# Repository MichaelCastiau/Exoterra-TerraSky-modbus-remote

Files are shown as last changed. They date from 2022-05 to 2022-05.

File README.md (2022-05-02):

# Exoterra Terrasky IR modbus enabled remote

These are the hardware schematics for a STM32 powered 38kHz IR remote that can 'learn' and then send out specfic signals for day, night and twilight lighting effects for the Exo Terrasky light. It makes use of the NEC protocol to learn and send commands.

The purpose is to automate an ExoTerra Terrasky using IR, since the default remote control doesn't have any timers.

RS-485 Modbus RTU can be used to send commands to change the lights, using a Modbus enabled PLC.

**The schematics are drawn using KiCad**

The firmware repository can be found [here](https://github.com/MichaelCastiau/Exoterra-Terrasky-modbus-remote-firmware/).

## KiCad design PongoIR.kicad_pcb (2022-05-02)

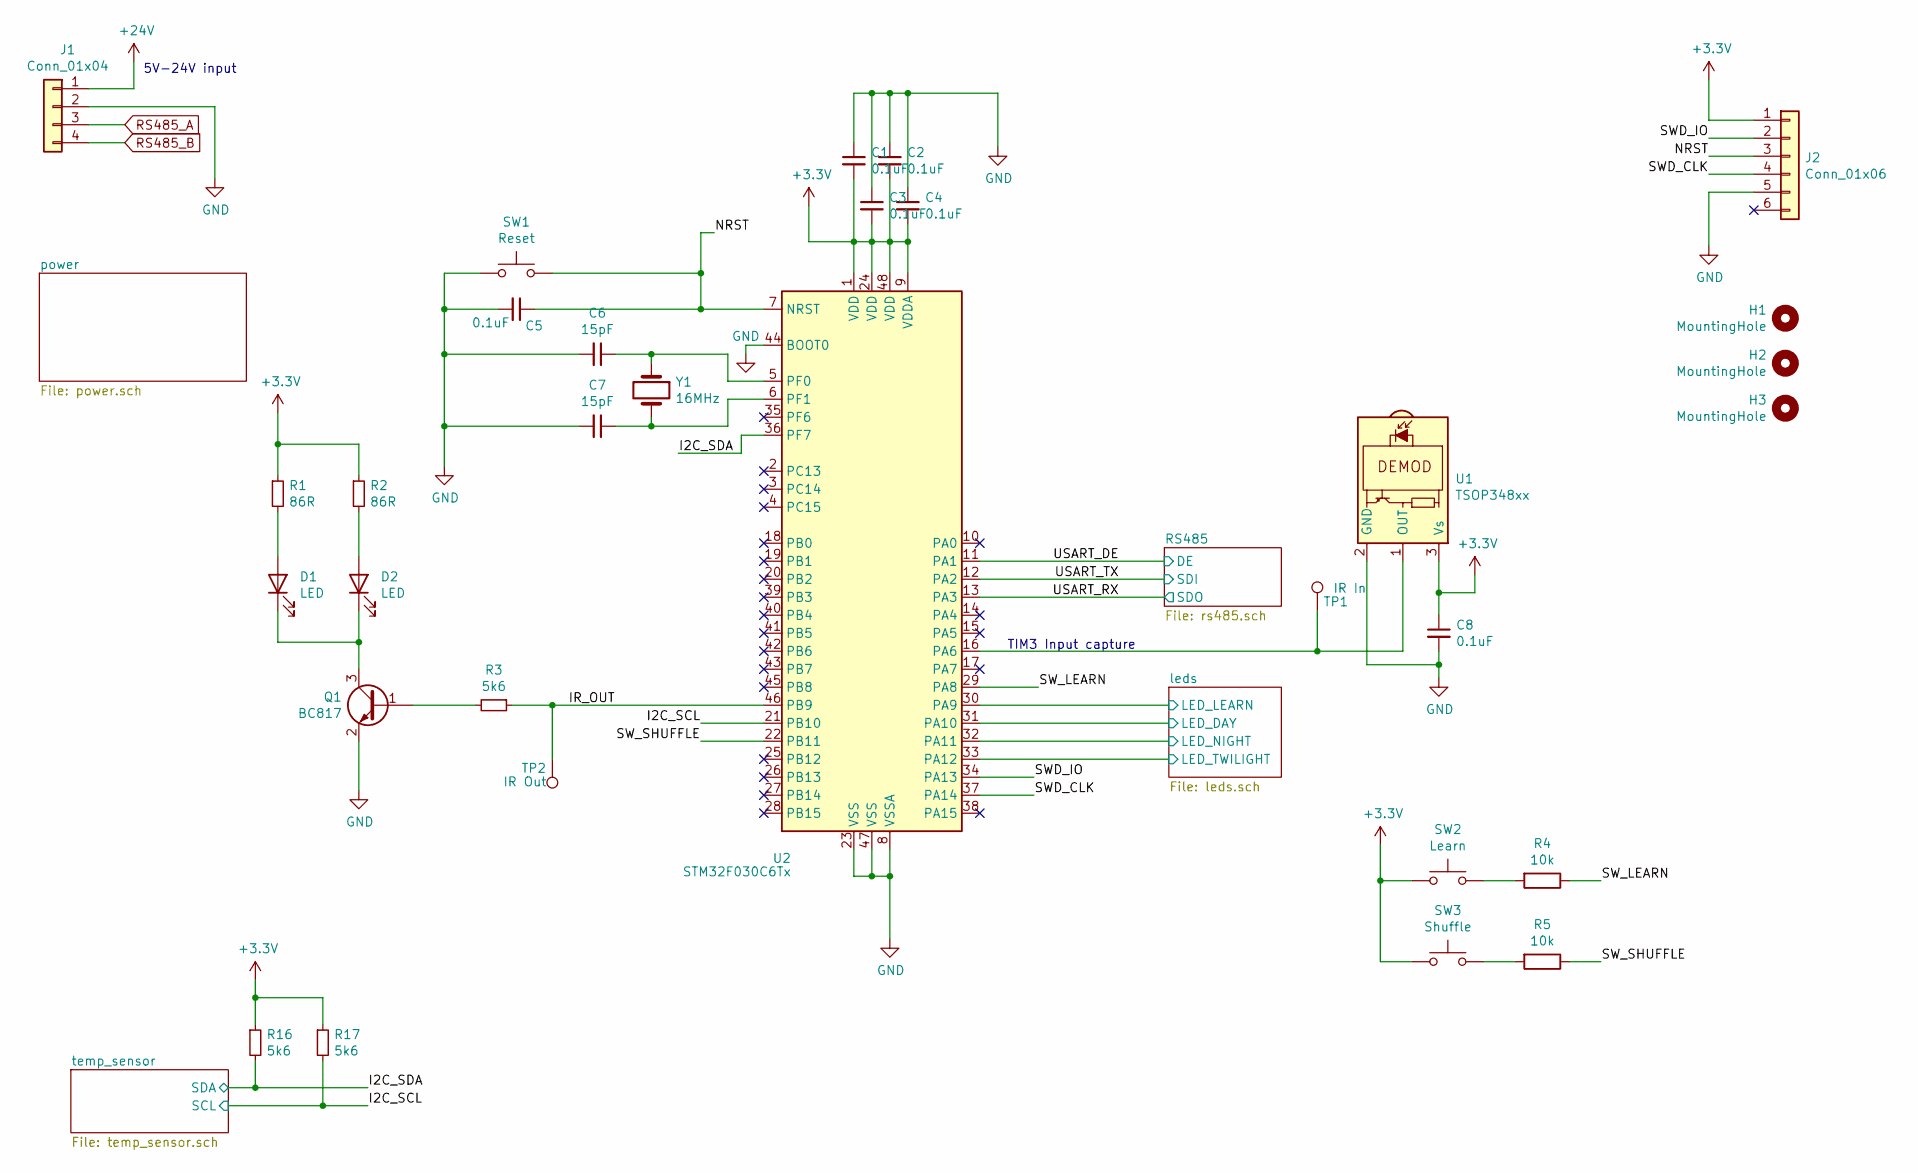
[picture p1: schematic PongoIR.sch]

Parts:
C1, C2, C3, C4, C5, C8: 0.1uF; C_0402_1005Metric
C6, C7: 15pF; C_0402_1005Metric
D1, D2: LED; LED_D5.0mm_Horizontal_O1.27mm_Z3.0mm_IRGrey
H1, H2, H3: MountingHole; MountingHole_3.2mm_M3_DIN965_Pad
J1: Conn_01x04; PhoenixContact_MSTBA_2,5_4-G-5,08_1x04_P5.08mm_Horizontal
J2: Conn_01x06; Tag-Connect_TC2030-IDC-FP_2x03_P1.27mm_Vertical
Q1: BC817; SOT-23
R1, R2: 86R; R_0402_1005Metric
R3, R16, R17: 5k6; R_0402_1005Metric
R4, R5: 10k; R_0402_1005Metric
SW1: Reset; SW_Push_1P1T_NO_CK_KMR2
SW2: Learn; SW_Push_1P1T_NO_6x6mm_H9.5mm
SW3: Shuffle; SW_Push_1P1T_NO_6x6mm_H9.5mm
TP1: IR In; TestPoint_Pad_D1.5mm
TP2: IR Out; TestPoint_Pad_D1.5mm
U1: TSOP348xx; Vishay_MOLD-3Pin
U2: STM32F030C6Tx; LQFP-48_7x7mm_P0.5mm
Y1: 16MHz; Crystal_SMD_HC49-SD

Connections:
+3V3: C1.2, C2.2, C3.2, C4.2, C8.1, J2.1, R1.1, R2.1, R16.1, R17.1, SW2.1, SW3.1, U1.3 (Vs), U2.1 (VDD), U2.9 (VDDA), U2.24 (VDD), U2.48 (VDD); also elsewhere on the board
+24V: J1.1; also elsewhere on the board
/I2C_SCL: R17.2, U2.21 (PB10); also elsewhere on the board
/I2C_SDA: R16.2, U2.36 (PF7); also elsewhere on the board
/IR_OUT: R3.1, TP2.1, U2.46 (PB9)
/NRST: C5.1, J2.3, SW1.2, U2.7 (NRST)
/SWD_CLK: J2.4, U2.37 (PA14)
/SWD_IO: J2.2, U2.34 (PA13)
/SW_LEARN: R4.1, U2.29 (PA8)
/SW_SHUFFLE: R5.1, U2.22 (PB11)
/USART_DE: U2.11 (PA1); also elsewhere on the board
/USART_RX: U2.13 (PA3); also elsewhere on the board
/USART_TX: U2.12 (PA2); also elsewhere on the board
/leds/LED_DAY: U2.31 (PA10); also elsewhere on the board
/leds/LED_LEARN: U2.30 (PA9); also elsewhere on the board
/leds/LED_NIGHT: U2.32 (PA11); also elsewhere on the board
/leds/LED_TWILIGHT: U2.33 (PA12); also elsewhere on the board
GND: C1.1, C2.1, C3.1, C4.1, C5.2, C6.2, C7.2, C8.2, J1.2, J2.5, Q1.2 (E), SW1.1, U1.2 (GND), U2.8 (VSSA), U2.23 (VSS), U2.44 (BOOT0), U2.47 (VSS); also elsewhere on the board
unnamed: C6.1, U2.5 (PF0), Y1.1
unnamed: C7.1, U2.6 (PF1), Y1.2
unnamed: D1.1 (K), D2.1 (K), Q1.3 (C)
unnamed: D1.2 (A), R1.2
unnamed: D2.2 (A), R2.2
unnamed: Q1.1 (B), R3.2
unnamed: R4.2, SW2.2
unnamed: R5.2, SW3.2
unnamed: TP1.1, U1.1 (OUT), U2.16 (PA6)
RS485_A: J1.3; also elsewhere on the board
RS485_B: J1.4; also elsewhere on the board

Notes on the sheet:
5V-24V input
TIM3 Input capture

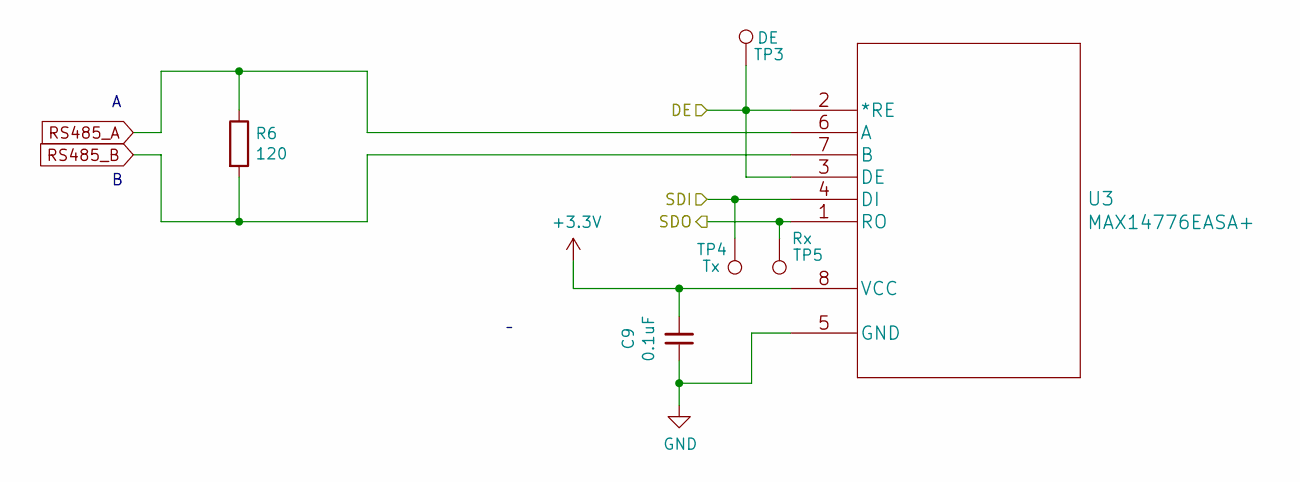
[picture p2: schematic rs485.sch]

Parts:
C9: 0.1uF; C_0402_1005Metric
R6: 120; R_0402_1005Metric
TP3: DE; TestPoint_Pad_D1.5mm
TP4: Tx; TestPoint_Pad_D1.5mm
TP5: Rx; TestPoint_Pad_D1.5mm
U3: MAX14776EASA+; MAX14776E

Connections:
+3V3: C9.2, U3.8 (VCC); also elsewhere on the board
/USART_DE: TP3.1, U3.2 (*RE), U3.3 (DE); also elsewhere on the board
/USART_RX: TP5.1, U3.1 (RO); also elsewhere on the board
/USART_TX: TP4.1, U3.4 (DI); also elsewhere on the board
GND: C9.1, U3.5 (GND); also elsewhere on the board
RS485_A: R6.1, U3.6 (A); also elsewhere on the board
RS485_B: R6.2, U3.7 (B); also elsewhere on the board

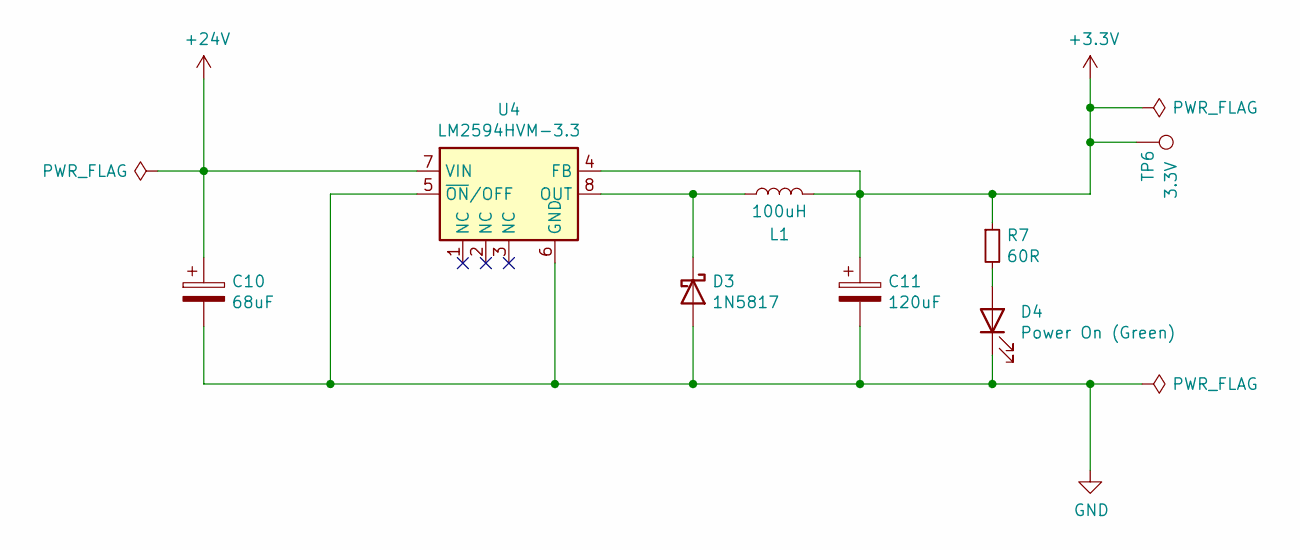
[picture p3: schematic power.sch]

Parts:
C10: 68uF; CP_Elec_5x5.4
C11: 120uF; CP_Radial_D5.0mm_P2.50mm
D3: 1N5817; D_SOD-123
D4: Power On (Green); LED_0805_2012Metric
L1: 100uH; L_1812_4532Metric
R7: 60R; R_0402_1005Metric
TP6: 3.3V; TestPoint_Pad_D1.5mm
U4: LM2594HVM-3.3; SOIC-8_3.9x4.9mm_P1.27mm

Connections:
+3V3: C11.1, L1.2, R7.1, TP6.1, U4.4 (FB); also elsewhere on the board
+24V: C10.1, U4.7 (VIN); also elsewhere on the board
GND: C10.2, C11.2, D3.2 (A), D4.1 (K), U4.5 (~ON~/OFF), U4.6 (GND); also elsewhere on the board
unnamed: D3.1 (K), L1.1, U4.8 (OUT)
unnamed: D4.2 (A), R7.2

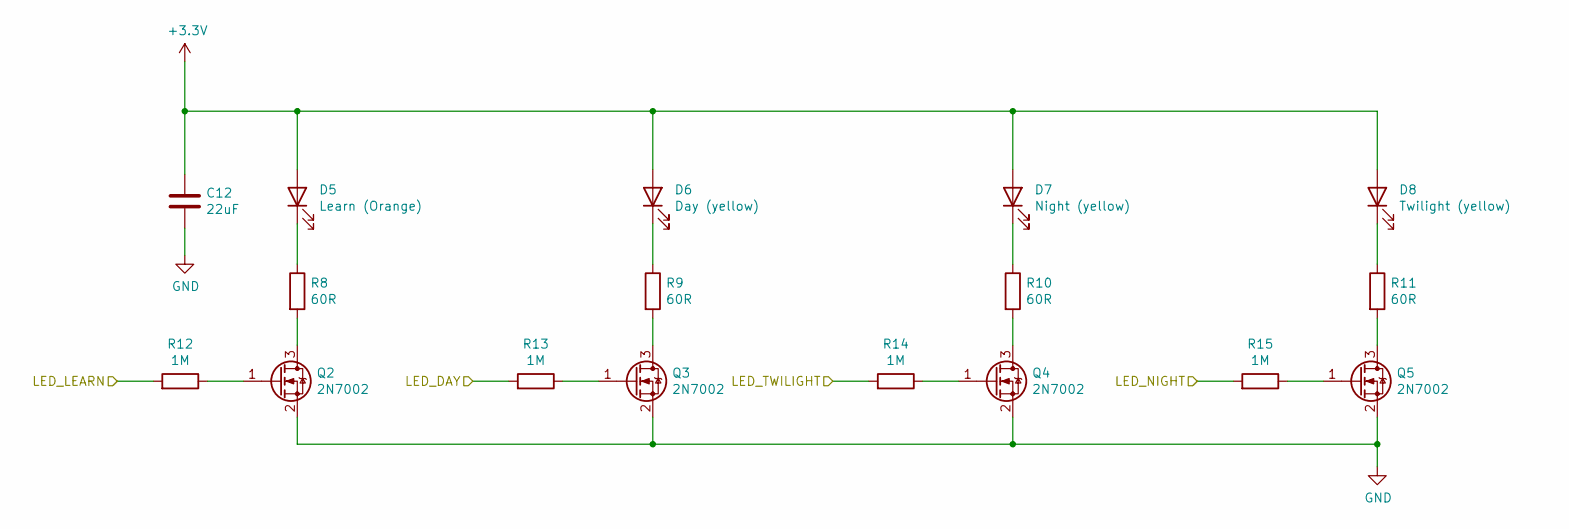
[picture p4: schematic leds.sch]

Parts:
C12: 22uF; C_0805_2012Metric
D5: Learn (Orange); LED_0805_2012Metric
D6: Day (yellow); LED_0805_2012Metric
D7: Night (yellow); LED_0805_2012Metric
D8: Twilight (yellow); LED_0805_2012Metric
Q2, Q3, Q4, Q5: 2N7002; SOT-23
R8, R9, R10, R11: 60R; R_0402_1005Metric
R12, R13, R14, R15: 1M; R_0402_1005Metric

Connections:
+3V3: C12.1, D5.2 (A), D6.2 (A), D7.2 (A), D8.2 (A); also elsewhere on the board
/leds/LED_DAY: R13.2; also elsewhere on the board
/leds/LED_LEARN: R12.2; also elsewhere on the board
/leds/LED_NIGHT: R15.2; also elsewhere on the board
/leds/LED_TWILIGHT: R14.2; also elsewhere on the board
GND: C12.2, Q2.2 (S), Q3.2 (S), Q4.2 (S), Q5.2 (S); also elsewhere on the board
unnamed: D5.1 (K), R8.1
unnamed: D6.1 (K), R9.1
unnamed: D7.1 (K), R10.1
unnamed: D8.1 (K), R11.1
unnamed: Q2.1 (G), R12.1
unnamed: Q2.3 (D), R8.2
unnamed: Q3.1 (G), R13.1
unnamed: Q3.3 (D), R9.2
unnamed: Q4.1 (G), R14.1
unnamed: Q4.3 (D), R10.2
unnamed: Q5.1 (G), R15.1
unnamed: Q5.3 (D), R11.2

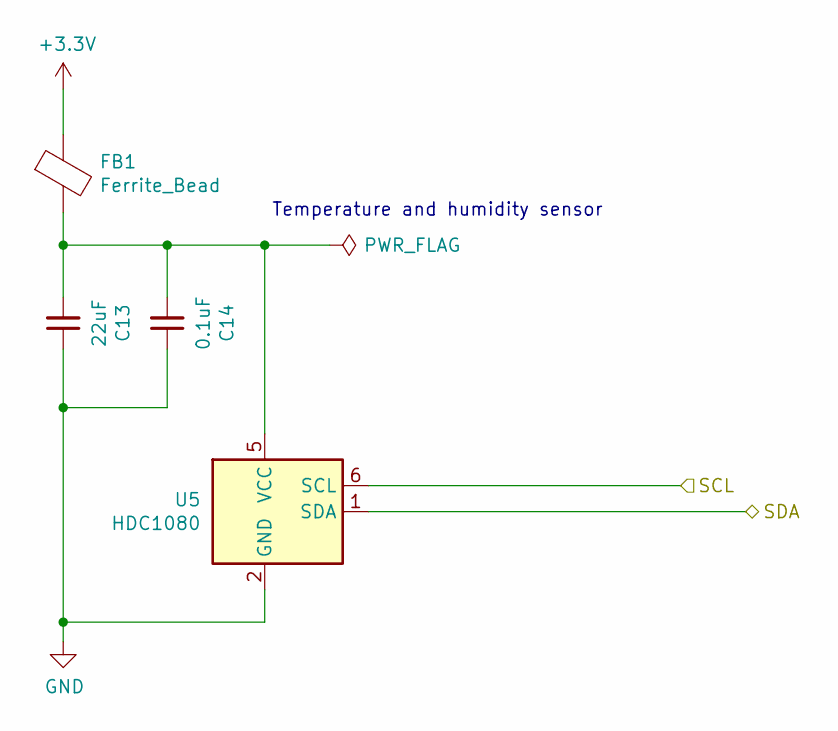
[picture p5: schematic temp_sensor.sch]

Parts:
C13: 22uF; C_0805_2012Metric
C14: 0.1uF; C_0402_1005Metric
FB1: Ferrite_Bead; R_0805_2012Metric
U5: HDC1080; Texas_PWSON-N6

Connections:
+3V3: FB1.1; also elsewhere on the board
/I2C_SCL: U5.6 (SCL); also elsewhere on the board
/I2C_SDA: U5.1 (SDA); also elsewhere on the board
GND: C13.1, C14.1, U5.2 (GND); also elsewhere on the board
unnamed: C13.2, C14.2, FB1.2, U5.5 (VCC)

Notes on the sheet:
Temperature and humidity sensor

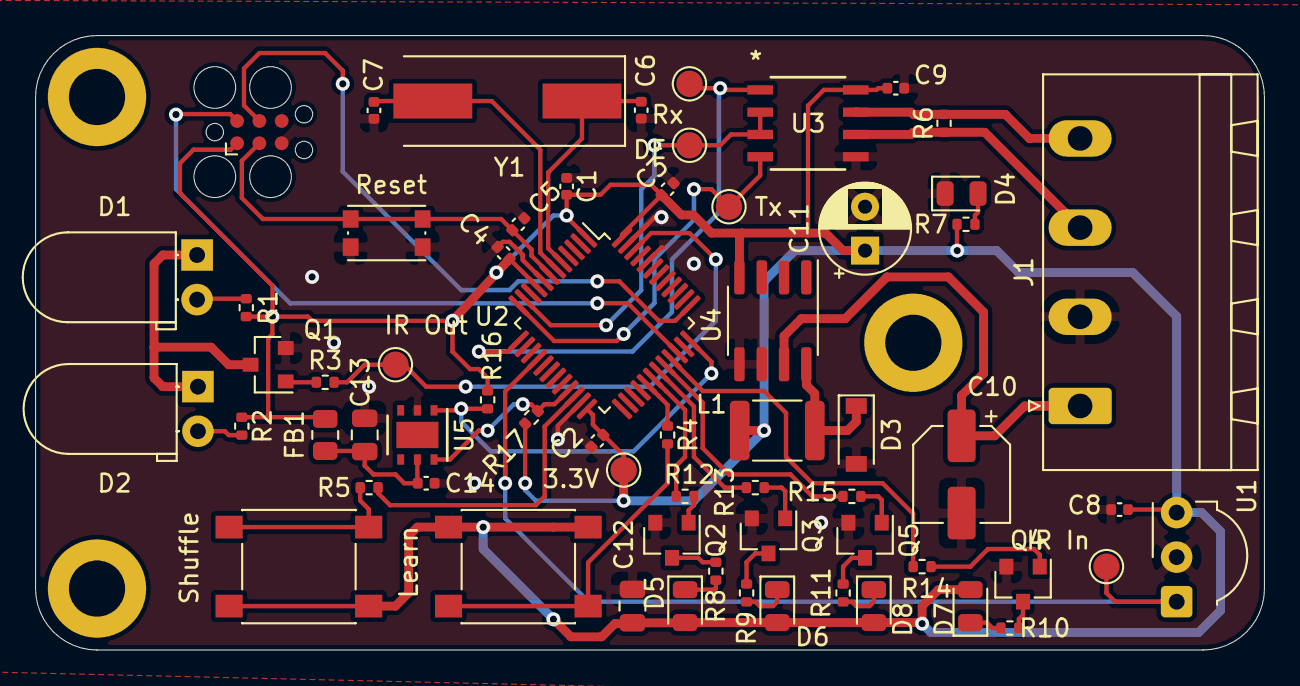
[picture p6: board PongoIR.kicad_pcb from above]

Board: 2 copper layers, 70.0 x 35.0 mm, 66 parts (0 on the bottom side), 44 nets.

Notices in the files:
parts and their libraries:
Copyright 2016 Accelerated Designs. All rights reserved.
